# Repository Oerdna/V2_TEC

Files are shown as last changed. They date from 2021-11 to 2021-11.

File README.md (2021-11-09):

# V2_TEC
Redesigned PCB for simultaneous Peltier control and surface resistance measurement

------

## Composition
The complex consists of two boards - Signal and Power. The power acts like as a controller of the Peltier element. Signal measures surface resistance and temperature.
In the table, the top line is the signal board. Lower - power. Drawings as part of a work of art.

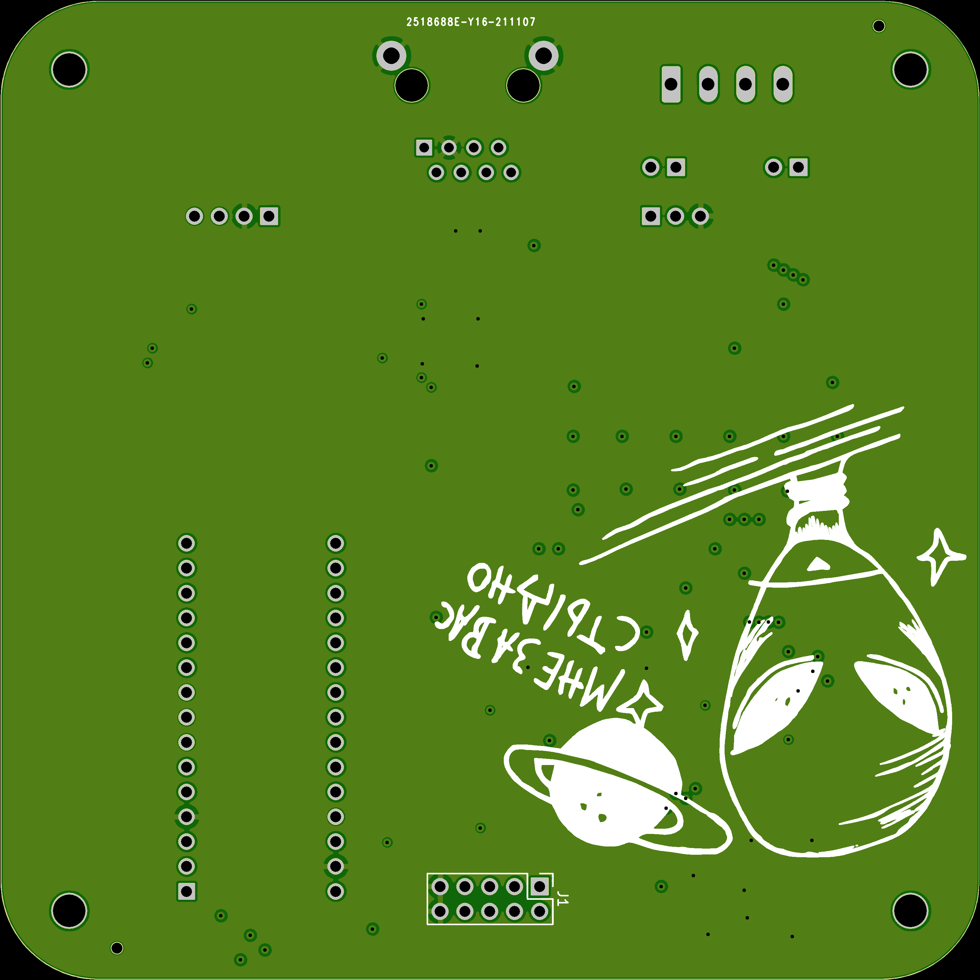
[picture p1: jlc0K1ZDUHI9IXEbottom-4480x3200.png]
Signal_top
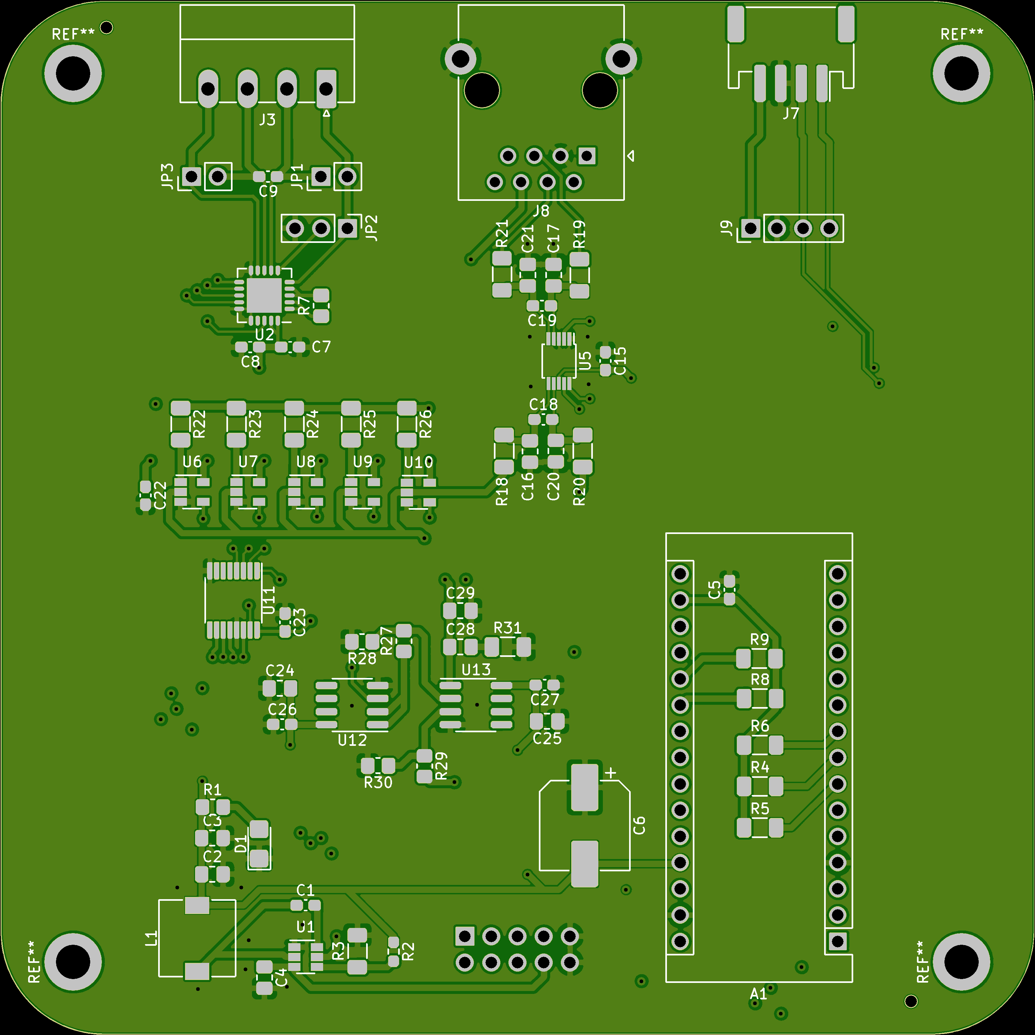
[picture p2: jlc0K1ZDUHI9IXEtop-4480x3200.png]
Signal_back
|  |  |
| --- | --- |
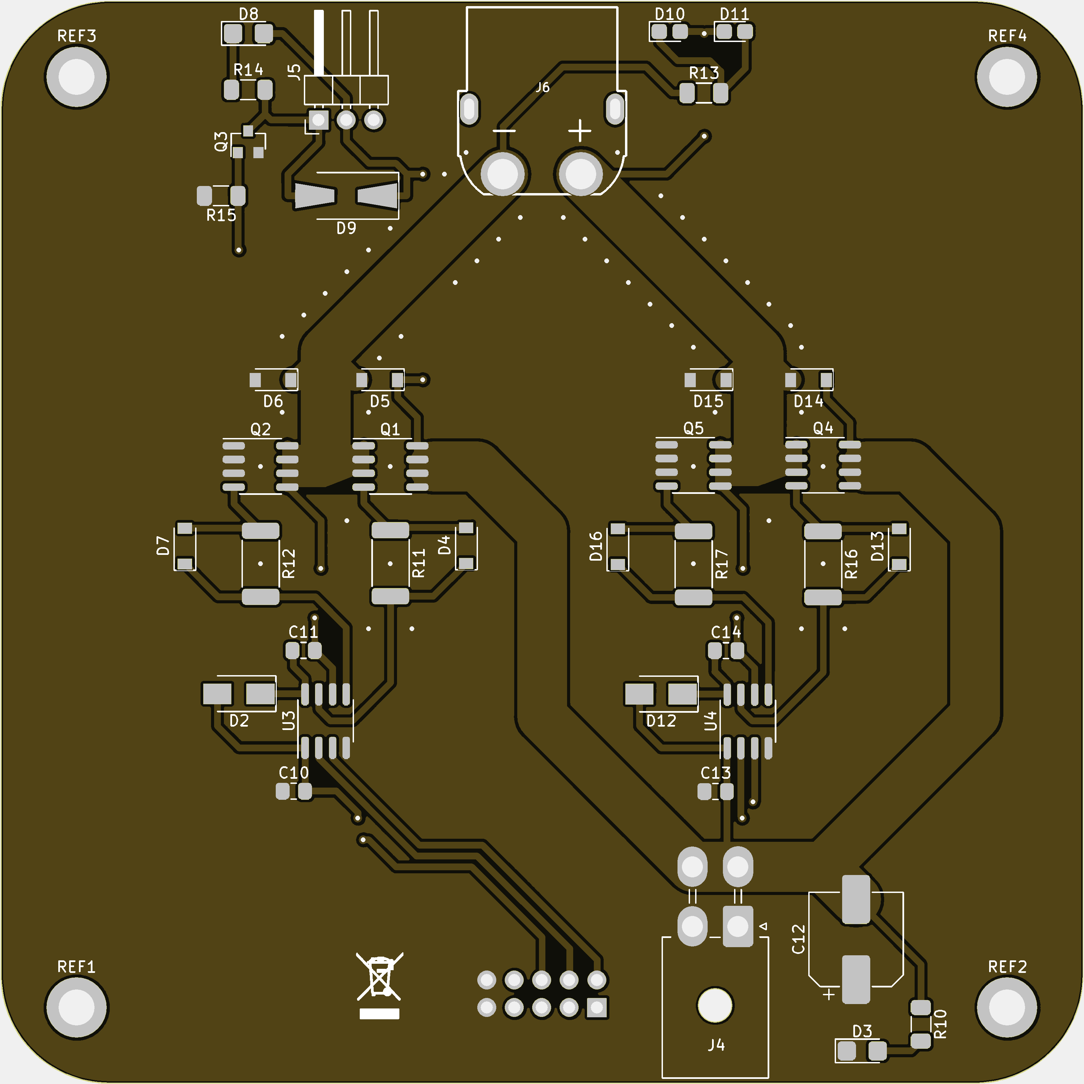
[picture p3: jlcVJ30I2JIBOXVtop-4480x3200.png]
Power_top
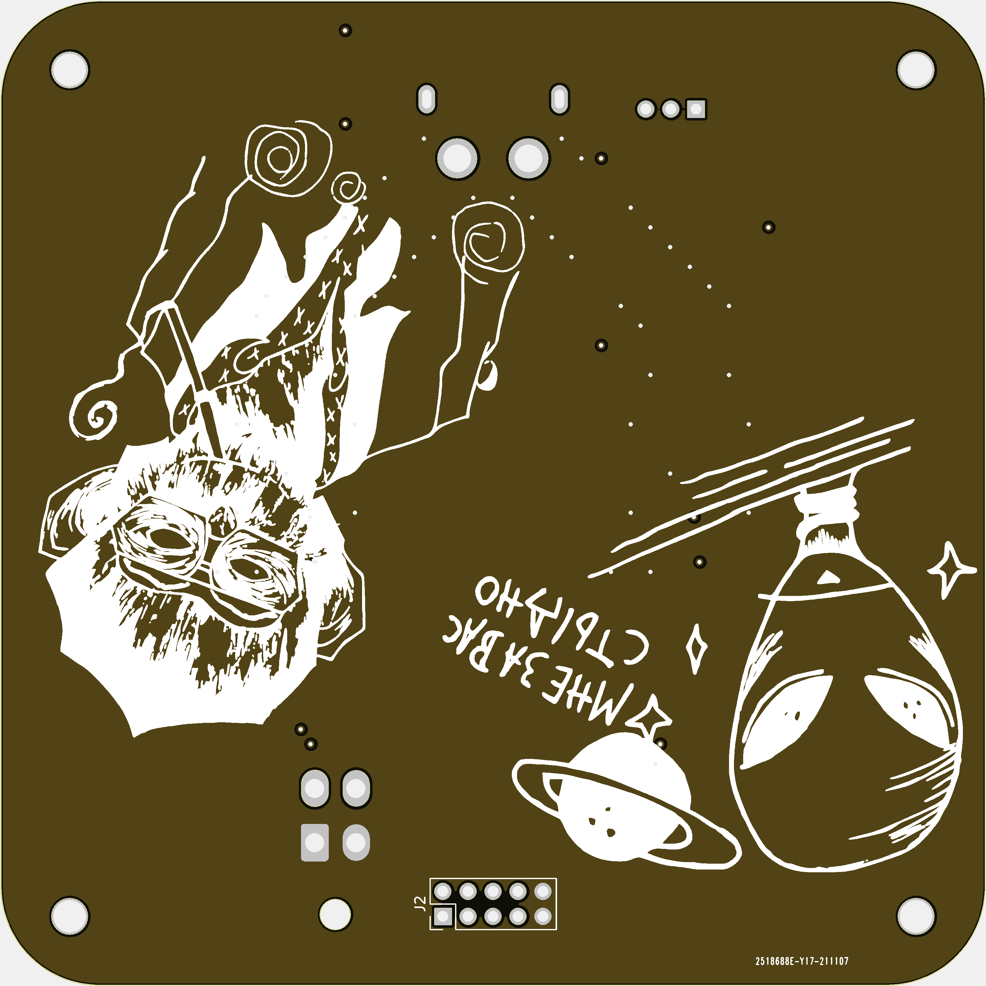
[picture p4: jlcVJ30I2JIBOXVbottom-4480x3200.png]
Power_back
|  |  |

More details about the device can be understood from the schematic drawing [here](https://github.com/Oerdna/V2_TEC/blob/main/TEC2/TEC2.pdf). The notes are in Russian.

The controller for the complex is `STM32L432KC Nucleo`.

## Reference Information:
* To control the Peltier element, a `100 kHz PWM` is used.
* `IRS2104` is used to control transistors.
* The measurement of surface resistance is carried out by the `four-probe method`.
* Temperature measurement is carried out by `pt100`.
* There is an additional port for the `I2C` protocol

## 4point_probe

 | 4PP | Four point probe is used to measure resistive properties of semiconductor wafers and thin films [[1](https://www.pveducation.org/pvcdrom/characterisation/four-point-probe-resistivity-measurements)]. |
| ------------------------------------------------------------ | ------------------------------------------------------------ |

In this case are studing the I - V characteristic of an element depending on the temperature of the sample. It is important to understand the I – V characteristic near the metal-insulator phase transition (MIT), which is about 68 degrees Celsius. You must understand that the ultimate goal is to stabilize the temperature to a specific value. More about the TEC control [[2](https://www.maximintegrated.com/en/design/technical-documents/tutorials/1/1757.html)]

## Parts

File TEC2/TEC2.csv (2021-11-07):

Comment | Designator | Footprint | LCSC
Arduino_Nano_v3.x | A1 | Module:Arduino_Nano | ~
1uF | C11,C14 | Capacitor_SMD:C_0805_2012Metric_Pad1.18x1.45mm_HandSolder | C28323
6nF | C16,C17,C20,C21,C29 | Capacitor_SMD:C_0805_2012Metric_Pad1.18x1.45mm_HandSolder | C1755
62nF | C18,C19 | Capacitor_SMD:C_0603_1608Metric_Pad1.08x0.95mm_HandSolder | C31658
470nf | C28 | Capacitor_SMD:C_0805_2012Metric_Pad1.18x1.45mm_HandSolder | C13967
10uF | C2,C3,C4,C10,C13,C24,C25 | Capacitor_SMD:C_0805_2012Metric_Pad1.18x1.45mm_HandSolder | C440198
100nF | C1,C5,C7,C8,C9,C15,C22,C23,C26,C27 | Capacitor_SMD:C_0603_1608Metric_Pad1.08x0.95mm_HandSolder | C14663
220uF | C6,C12 | Capacitor_SMD:CP_Elec_8x10.5 | ~
5V_LED | D1 | LED_SMD:LED_1206_3216Metric_Castellated | ~
LED | D10,D11 | LED_SMD:LED_0805_2012Metric_Castellated | ~
US2MA | D2,D12 | Diode_SMD:D_SMA | ~
1N4148W | D4,D5,D6,D7,D13,D14,D15,D16 | Diode_SMD:D_SOD-123 | ~
12V_LED | D3 | LED_SMD:LED_1206_3216Metric_Castellated | ~
FUN_LED | D8 | LED_SMD:LED_1206_3216Metric_Castellated | ~
1N4001 | D9 | Diode_SMD:D_SMA-SMB_Universal_Handsoldering | ~
J_PCB_UPPER | J1 | Connector_PinHeader_2.54mm:PinHeader_2x05_P2.54mm_Vertical | ~
J_PCB_DOWN | J2 | Connector_PinHeader_2.54mm:PinHeader_2x05_P2.54mm_Vertical | ~
ToPT100 | J3 | Connector_Phoenix_MC:PhoenixContact_MC_1,5_4-G-3.81_1x04_P3.81mm_Horizontal | ~
IN_12V_POWER | J4 | Connector_Molex:Molex_Mini-Fit_Jr_5569-04A2_2x02_P4.20mm_Horizontal | ~
J_COOLER | J5 | Connector_PinHeader_2.54mm:PinHeader_1x03_P2.54mm_Horizontal | ~
J_TERMO | J6 | XT60-PW:Amass_XT60PW-M | ~
I2C_Port | J7 | Connector_JST:JST_PH_S4B-PH-SM4-TB_1x04-1MP_P2.00mm_Horizontal | ~
RJ45_Shielded | J8 | Connector_RJ:RJ45_Ninigi_GE | ~
I2C_dbg | J9 | Connector_PinHeader_2.54mm:PinHeader_1x04_P2.54mm_Vertical | ~
SJ2 | JP1 | Connector_PinHeader_2.54mm:PinHeader_1x02_P2.54mm_Vertical | ~
SJ1 | JP2 | Connector_PinHeader_2.54mm:PinHeader_1x03_P2.54mm_Vertical | ~
SJ3 | JP3 | Connector_PinHeader_2.54mm:PinHeader_1x02_P2.54mm_Vertical | ~
4.7uH | L1 | Inductor_SMD:L_7.3x7.3_H4.5 | ~
FDV303N | Q3 | Package_TO_SOT_SMD:SOT-23 | ~
IRF7403 | Q1,Q2,Q4,Q5 | Package_SO:SOIC-8_3.9x4.9mm_P1.27mm | ~
430 | R1 | Resistor_SMD:R_0805_2012Metric_Pad1.20x1.40mm_HandSolder | C17710
1k | R10,R13,R14,R15,R25 | Resistor_SMD:R_1206_3216Metric_Pad1.30x1.75mm_HandSolder | C4410
47 | R11,R12,R16,R17 | Resistor_SMD:R_2512_6332Metric_Pad1.40x3.35mm_HandSolder | ~
56.2k | R2 | Resistor_SMD:R_0603_1608Metric_Pad0.98x0.95mm_HandSolder | C23206
1 | R22 | Resistor_SMD:R_1206_3216Metric_Pad1.30x1.75mm_HandSolder | C17928
10 | R23 | Resistor_SMD:R_1206_3216Metric_Pad1.30x1.75mm_HandSolder | C17903
20k | R27,R30 | Resistor_SMD:R_0805_2012Metric_Pad1.20x1.40mm_HandSolder | C4328
13k | R28,R29 | Resistor_SMD:R_0805_2012Metric_Pad1.20x1.40mm_HandSolder | C17455
100 | R18,R19,R20,R21,R24,R31 | Resistor_SMD:R_1206_3216Metric_Pad1.30x1.75mm_HandSolder | C17901
390 | R7 | Resistor_SMD:R_0805_2012Metric_Pad1.20x1.40mm_HandSolder | C17655
10k | R3,R4,R5,R6,R8,R9,R26 | Resistor_SMD:R_1206_3216Metric_Pad1.30x1.75mm_HandSolder | C17902
TPS562200 | U1 | Package_TO_SOT_SMD:SOT-23-6 | ~
TS5A3166DBVR | U6,U7,U8,U9,U10 | Package_TO_SOT_SMD:SOT-23-5 | ~
74HC595 | U11 | Package_SO:TSSOP-16_4.4x5mm_P0.65mm | ~
AD8572 | U12 | Package_SO:SOIC-8_3.9x4.9mm_P1.27mm | ~
AD8606ARZ | U13 | Package_SO:SOIC-8_3.9x4.9mm_P1.27mm | ~
MAX31865xTP | U2 | Package_DFN_QFN:TQFN-20-1EP_5x5mm_P0.65mm_EP3.25x3.25mm | ~
IR2104 | U3,U4 | Package_SO:SOIC-8_3.9x4.9mm_P1.27mm | ~
ADS1115IDGS | U5 | Package_SO:TSSOP-10_3x3mm_P0.5mm | ~

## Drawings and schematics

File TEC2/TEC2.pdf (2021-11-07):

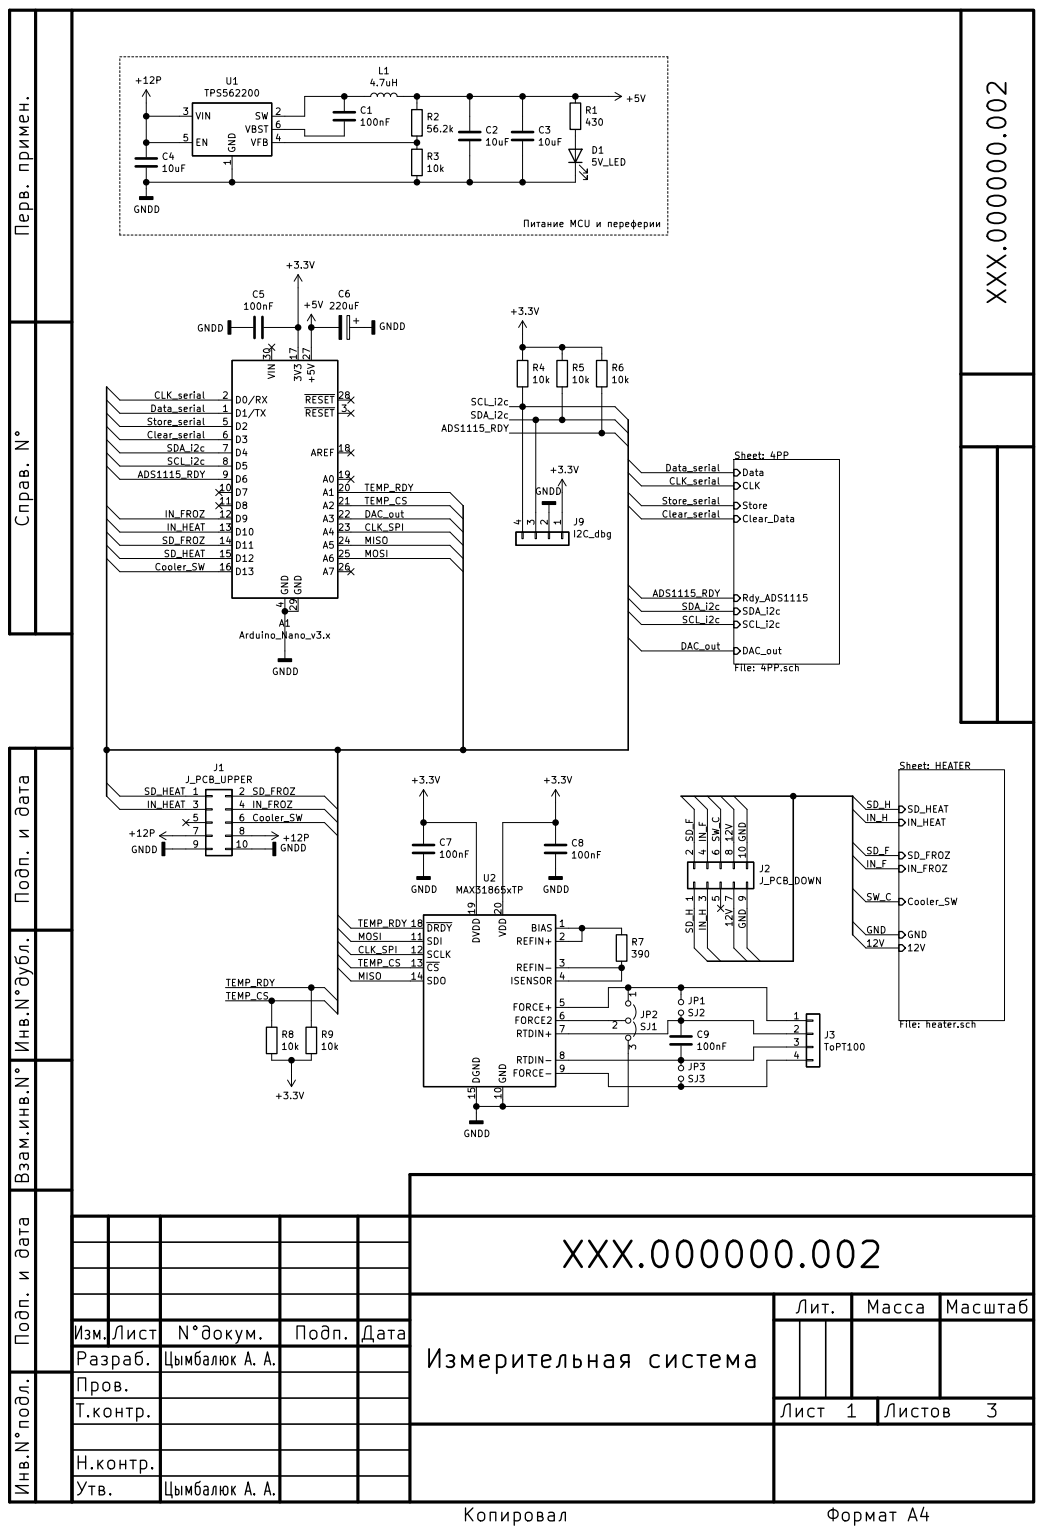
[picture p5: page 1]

1 SW 2 VIN 3 VFB 4 EN 5 VBST 6 U1 TPS562200 GNDD

Sheet: 4PP
File: 4PP.sch SCL_i2c SDA_i2c Data Clear_Data CLK
Store DAC_out Rdy_ADS1115

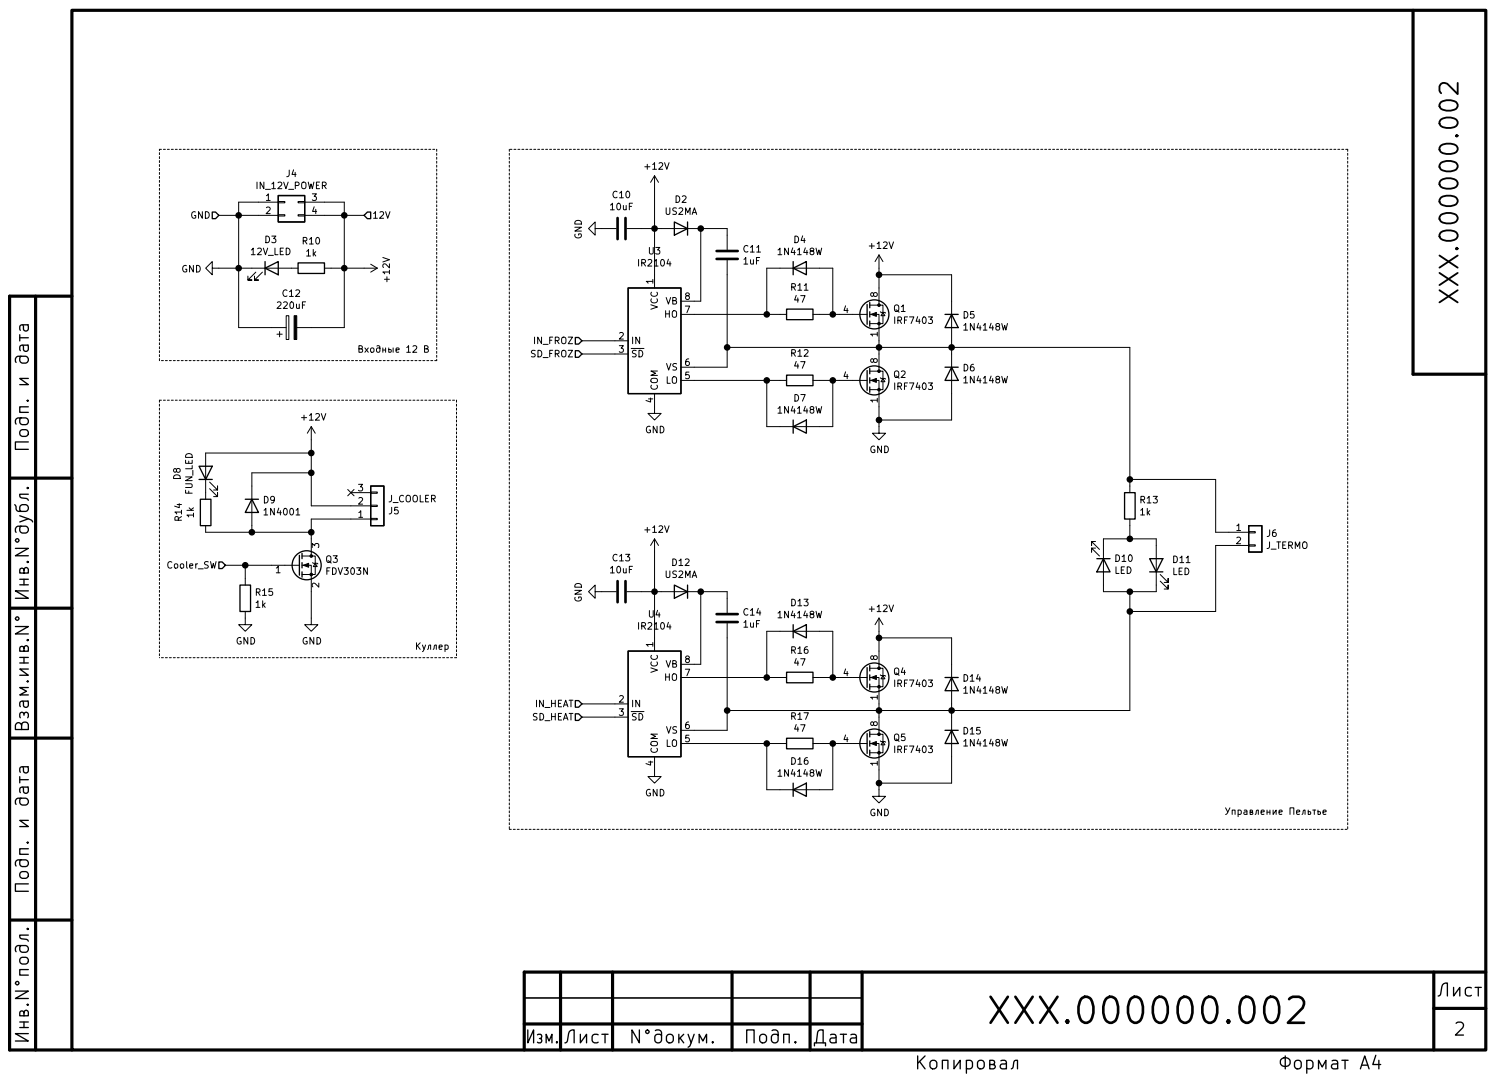
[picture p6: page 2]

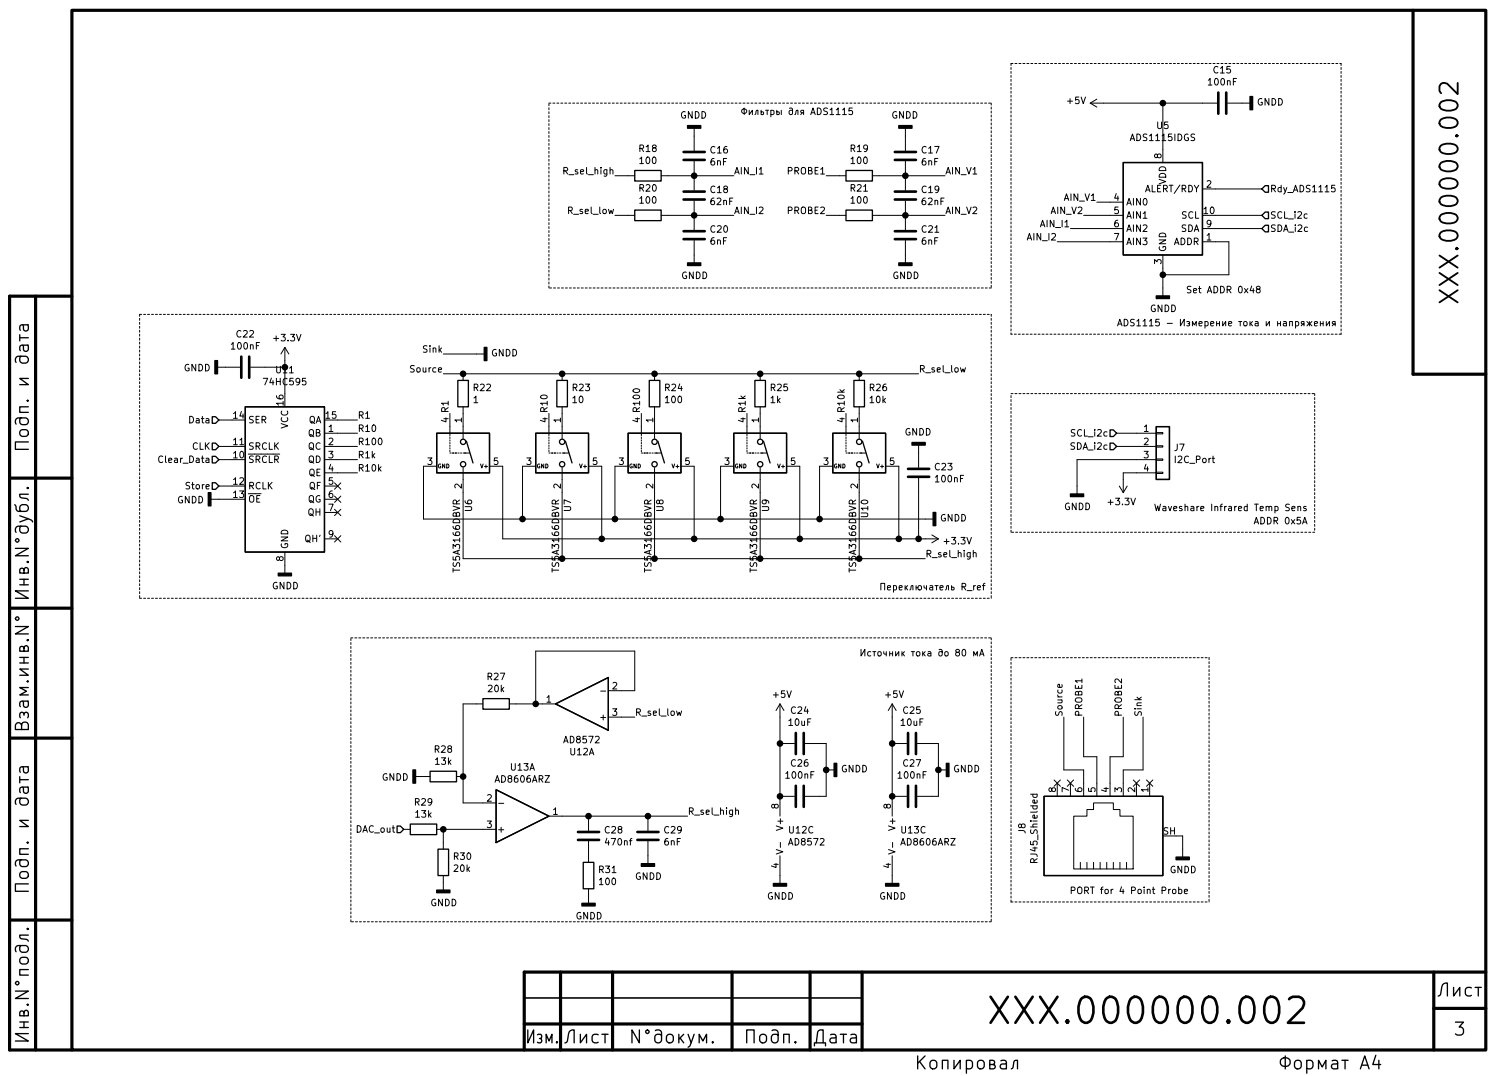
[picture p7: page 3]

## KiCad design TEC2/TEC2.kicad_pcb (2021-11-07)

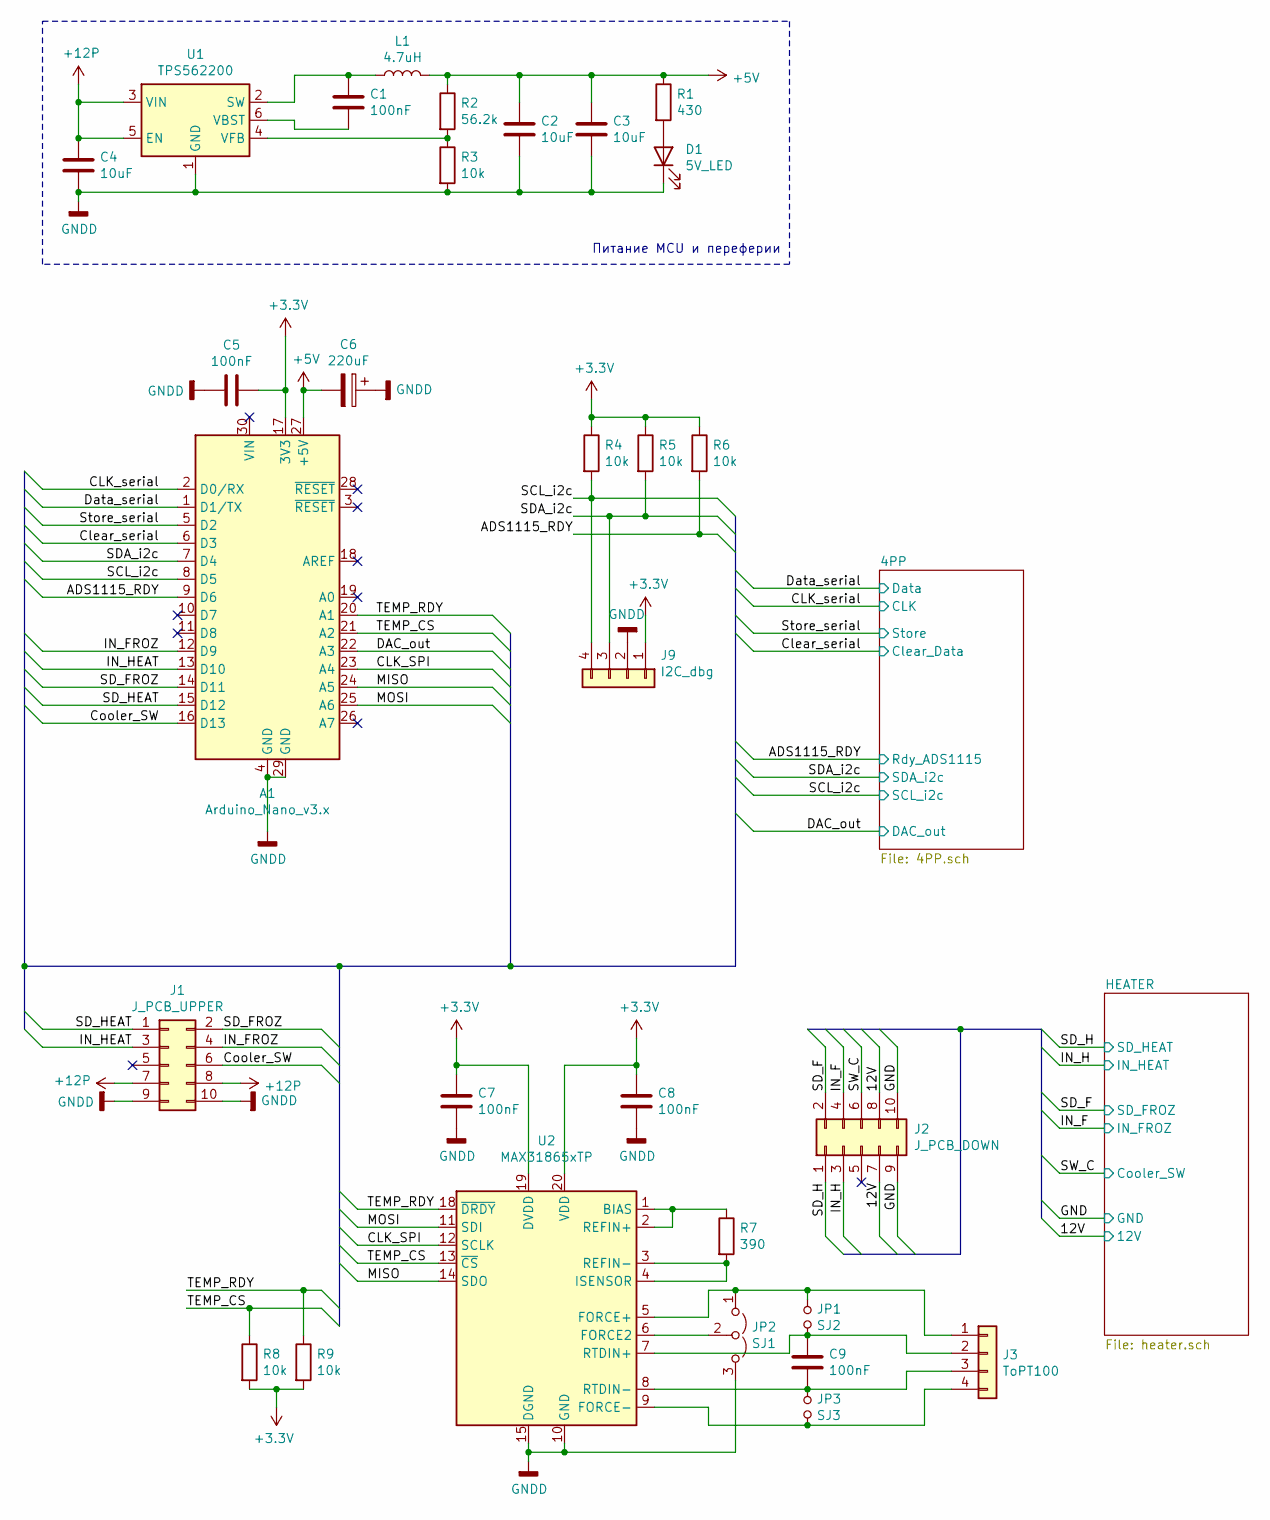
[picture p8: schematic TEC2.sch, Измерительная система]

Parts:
A1: Arduino_Nano_v3.x; Arduino_Nano
C1, C5, C7, C8, C9: 100nF; C_0603_1608Metric_Pad1.08x0.95mm_HandSolder; JLC 0603
C2, C3, C4: 10uF; C_0805_2012Metric_Pad1.18x1.45mm_HandSolder; JLC 0805
C6: 220uF; CP_Elec_8x10.5
D1: 5V_LED; LED_1206_3216Metric_Castellated
J1: J_PCB_UPPER; PinHeader_2x05_P2.54mm_Vertical
J2: J_PCB_DOWN; PinHeader_2x05_P2.54mm_Vertical
J3: ToPT100; PhoenixContact_MC_1,5_4-G-3.81_1x04_P3.81mm_Horizontal
J9: I2C_dbg; PinHeader_1x04_P2.54mm_Vertical
JP1: SJ2; PinHeader_1x02_P2.54mm_Vertical
JP2: SJ1; PinHeader_1x03_P2.54mm_Vertical
JP3: SJ3; PinHeader_1x02_P2.54mm_Vertical
L1: 4.7uH; L_7.3x7.3_H4.5
R1: 430; R_0805_2012Metric_Pad1.20x1.40mm_HandSolder; JLC 0805
R2: 56.2k; R_0603_1608Metric_Pad0.98x0.95mm_HandSolder; JLC 0603
R3, R4, R5, R6, R8, R9: 10k; R_1206_3216Metric_Pad1.30x1.75mm_HandSolder; JLC 1206
R7: 390; R_0805_2012Metric_Pad1.20x1.40mm_HandSolder; JLC 0805
U1: TPS562200; SOT-23-6
U2: MAX31865xTP; TQFN-20-1EP_5x5mm_P0.65mm_EP3.25x3.25mm

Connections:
+3V3: A1.17 (3V3), C5.1, C7.2, C8.1, J9.1, R4.1, R5.1, R6.1, R8.2, R9.2, U2.19 (DVDD), U2.20 (VDD); also elsewhere on the board
+5V: A1.27 (+5V), C2.1, C3.1, C6.2, L1.2, R1.1, R2.1; also elsewhere on the board
+12P: C4.1, J1.7, J1.8, U1.3 (VIN), U1.5 (EN)
+12V: J2.7, J2.8; also elsewhere on the board
/ADS1115_RDY: A1.9 (D6), R6.2; also elsewhere on the board
/CLK_SPI: A1.23 (A4), U2.12 (SCLK)
/CLK_serial: A1.2 (D0/RX); also elsewhere on the board
/Clear_serial: A1.6 (D3); also elsewhere on the board
/Cooler_SW: A1.16 (D13), J1.6
/DAC_out: A1.22 (A3); also elsewhere on the board
/Data_serial: A1.1 (D1/TX); also elsewhere on the board
/IN_F: J2.4; also elsewhere on the board
/IN_FROZ: A1.12 (D9), J1.4
/IN_H: J2.3; also elsewhere on the board
/IN_HEAT: A1.13 (D10), J1.3
/MISO: A1.24 (A5), U2.14 (SDO)
/MOSI: A1.25 (A6), U2.11 (SDI)
/SCL_i2c: A1.8 (D5), J9.4, R4.2; also elsewhere on the board
/SDA_i2c: A1.7 (D4), J9.3, R5.2; also elsewhere on the board
/SD_F: J2.2; also elsewhere on the board
/SD_FROZ: A1.14 (D11), J1.2
/SD_H: J2.1; also elsewhere on the board
/SD_HEAT: A1.15 (D12), J1.1
/SW_C: J2.6; also elsewhere on the board
/Store_serial: A1.5 (D2); also elsewhere on the board
/TEMP_CS: A1.21 (A2), R8.1, U2.13 (~CS)
/TEMP_RDY: A1.20 (A1), R9.1, U2.18 (~DRDY)
GND: J2.9, J2.10; also elsewhere on the board
GNDD: A1.4 (GND), A1.29 (GND), C2.2, C3.2, C4.2, C5.2, C6.1, C7.1, C8.2, D1.1 (K), J1.9, J1.10, J9.2, JP2.3 (B), R3.2, U1.1 (GND), U2.10 (GND), U2.15 (DGND), U2.16 (GND), U2.21 (GND); also elsewhere on the board
unnamed: C1.1, L1.1, U1.2 (SW)
unnamed: C1.2, U1.6 (VBST)
unnamed: C9.1, J3.2, JP1.1, U2.7 (RTDIN+)
unnamed: C9.2, J3.3, JP3.2, U2.8 (RTDIN-)
unnamed: D1.2 (A), R1.2
unnamed: J3.1, JP1.2, JP2.1 (A), U2.5 (FORCE+)
unnamed: J3.4, JP3.1, U2.9 (FORCE-)
unnamed: JP2.2 (C), U2.6 (FORCE2)
unnamed: R2.2, R3.1, U1.4 (VFB)
unnamed: R7.1, U2.1 (BIAS), U2.2 (REFIN+)
unnamed: R7.2, U2.3 (REFIN-), U2.4 (ISENSOR)

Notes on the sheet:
Питание MCU и переферии

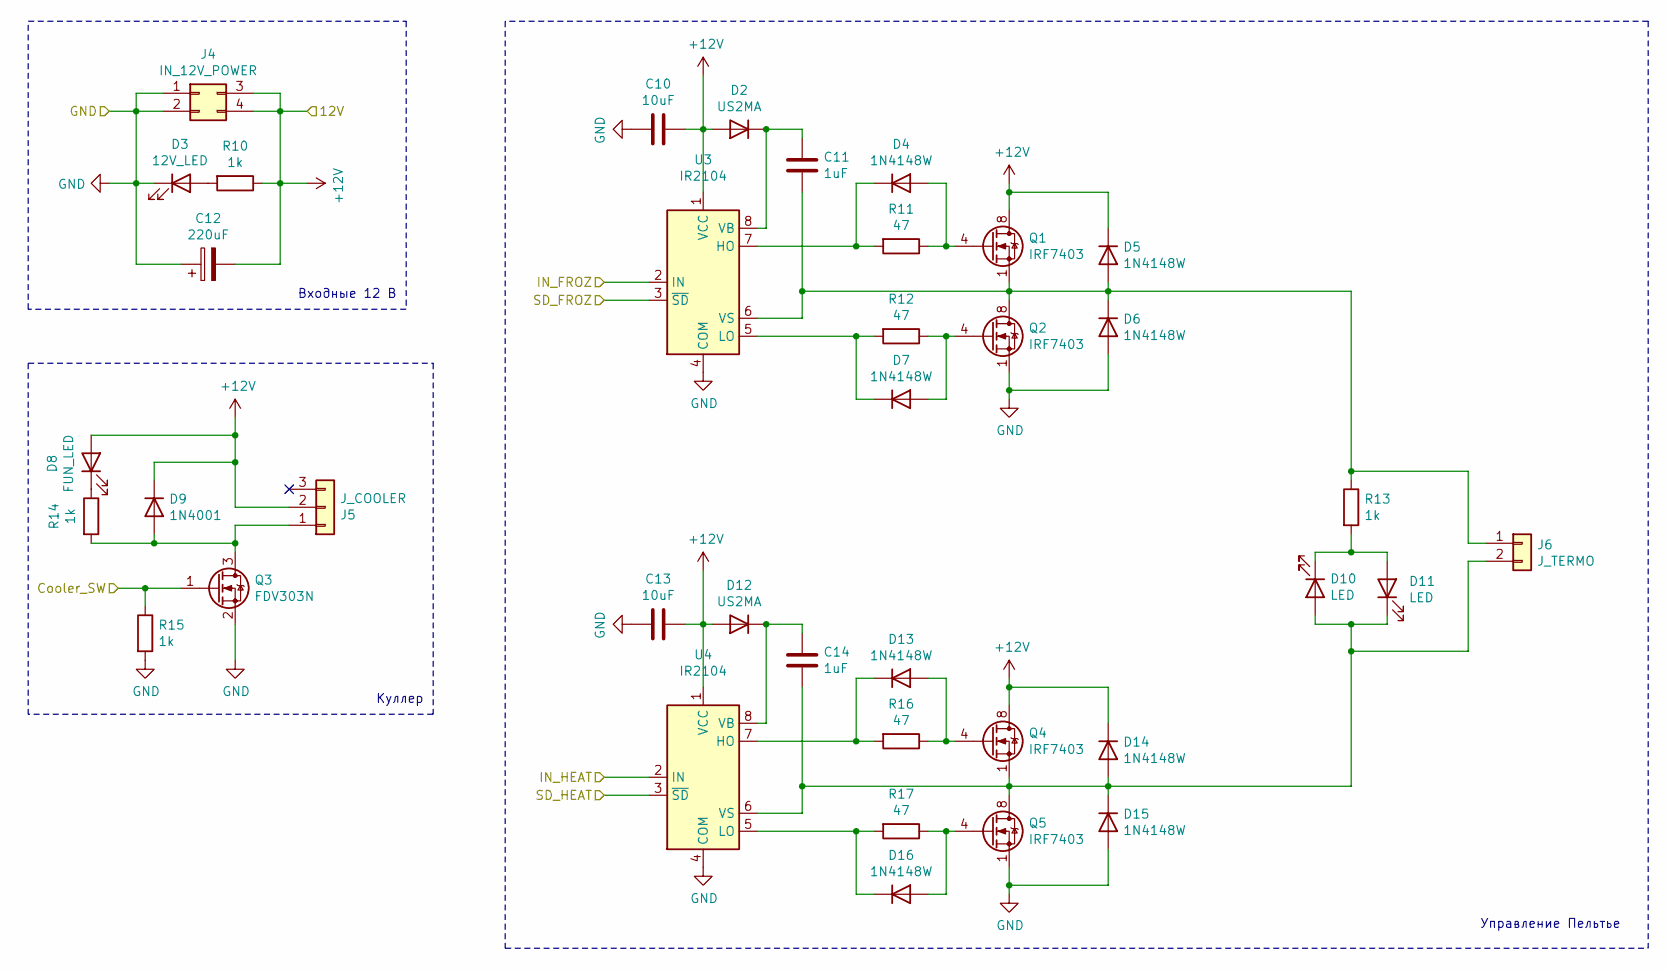
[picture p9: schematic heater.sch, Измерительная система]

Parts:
C10, C13: 10uF; C_0805_2012Metric_Pad1.18x1.45mm_HandSolder; JLC 0805
C11, C14: 1uF; C_0805_2012Metric_Pad1.18x1.45mm_HandSolder; JLC 0805
C12: 220uF; CP_Elec_8x10.5
D2, D12: US2MA; D_SMA
D3: 12V_LED; LED_1206_3216Metric_Castellated
D4, D5, D6, D7, D13, D14, D15, D16: 1N4148W; D_SOD-123
D8: FUN_LED; LED_1206_3216Metric_Castellated
D9: 1N4001; D_SMA-SMB_Universal_Handsoldering
D10, D11: LED; LED_0805_2012Metric_Castellated
J4: IN_12V_POWER; Molex_Mini-Fit_Jr_5569-04A2_2x02_P4.20mm_Horizontal
J5: J_COOLER; PinHeader_1x03_P2.54mm_Horizontal
J6: J_TERMO; Amass_XT60PW-M
Q1, Q2, Q4, Q5: IRF7403; SOIC-8_3.9x4.9mm_P1.27mm
Q3: FDV303N; SOT-23
R10, R13, R14, R15: 1k; R_1206_3216Metric_Pad1.30x1.75mm_HandSolder; JLC 1206
R11, R12, R16, R17: 47; R_2512_6332Metric_Pad1.40x3.35mm_HandSolder
U3, U4: IR2104; SOIC-8_3.9x4.9mm_P1.27mm

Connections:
+12V: C10.2, C12.2, C13.2, D2.2 (A), D5.1 (K), D8.2 (A), D9.1 (K), D12.2 (A), D14.1 (K), J4.3, J4.4, J5.2, Q1.5 (D), Q1.6 (D), Q1.7 (D), Q1.8 (D), Q4.5 (D), Q4.6 (D), Q4.7 (D), Q4.8 (D), R10.1, U3.1 (VCC), U4.1 (VCC); also elsewhere on the board
/IN_F: U3.2 (IN); also elsewhere on the board
/IN_H: U4.2 (IN); also elsewhere on the board
/SD_F: U3.3 (~SD); also elsewhere on the board
/SD_H: U4.3 (~SD); also elsewhere on the board
/SW_C: Q3.1 (G), R15.1; also elsewhere on the board
GND: C10.1, C12.1, C13.1, D3.1 (K), D6.2 (A), D15.2 (A), J4.1, J4.2, Q2.1 (S), Q2.2 (S), Q2.3 (S), Q3.2 (S), Q5.1 (S), Q5.2 (S), Q5.3 (S), R15.2, U3.4 (COM), U4.4 (COM); also elsewhere on the board
unnamed: C11.1, D2.1 (K), U3.8 (VB)
unnamed: C11.2, D5.2 (A), D6.1 (K), J6.1, Q1.1 (S), Q1.2 (S), Q1.3 (S), Q2.5 (D), Q2.6 (D), Q2.7 (D), Q2.8 (D), R13.1, U3.6 (VS)
unnamed: C14.1, D12.1 (K), U4.8 (VB)
unnamed: C14.2, D10.2 (A), D11.1 (K), D14.2 (A), D15.1 (K), J6.2, Q4.1 (S), Q4.2 (S), Q4.3 (S), Q5.5 (D), Q5.6 (D), Q5.7 (D), Q5.8 (D), U4.6 (VS)
unnamed: D3.2 (A), R10.2
unnamed: D4.1 (K), R11.2, U3.7 (HO)
unnamed: D4.2 (A), Q1.4 (G), R11.1
unnamed: D7.1 (K), R12.2, U3.5 (LO)
unnamed: D7.2 (A), Q2.4 (G), R12.1
unnamed: D8.1 (K), R14.1
unnamed: D9.2 (A), J5.1, Q3.3 (D), R14.2
unnamed: D10.1 (K), D11.2 (A), R13.2
unnamed: D13.1 (K), R16.2, U4.7 (HO)
unnamed: D13.2 (A), Q4.4 (G), R16.1
unnamed: D16.1 (K), R17.2, U4.5 (LO)
unnamed: D16.2 (A), Q5.4 (G), R17.1

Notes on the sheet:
Куллер
Управление Пельтье
Входные 12 В

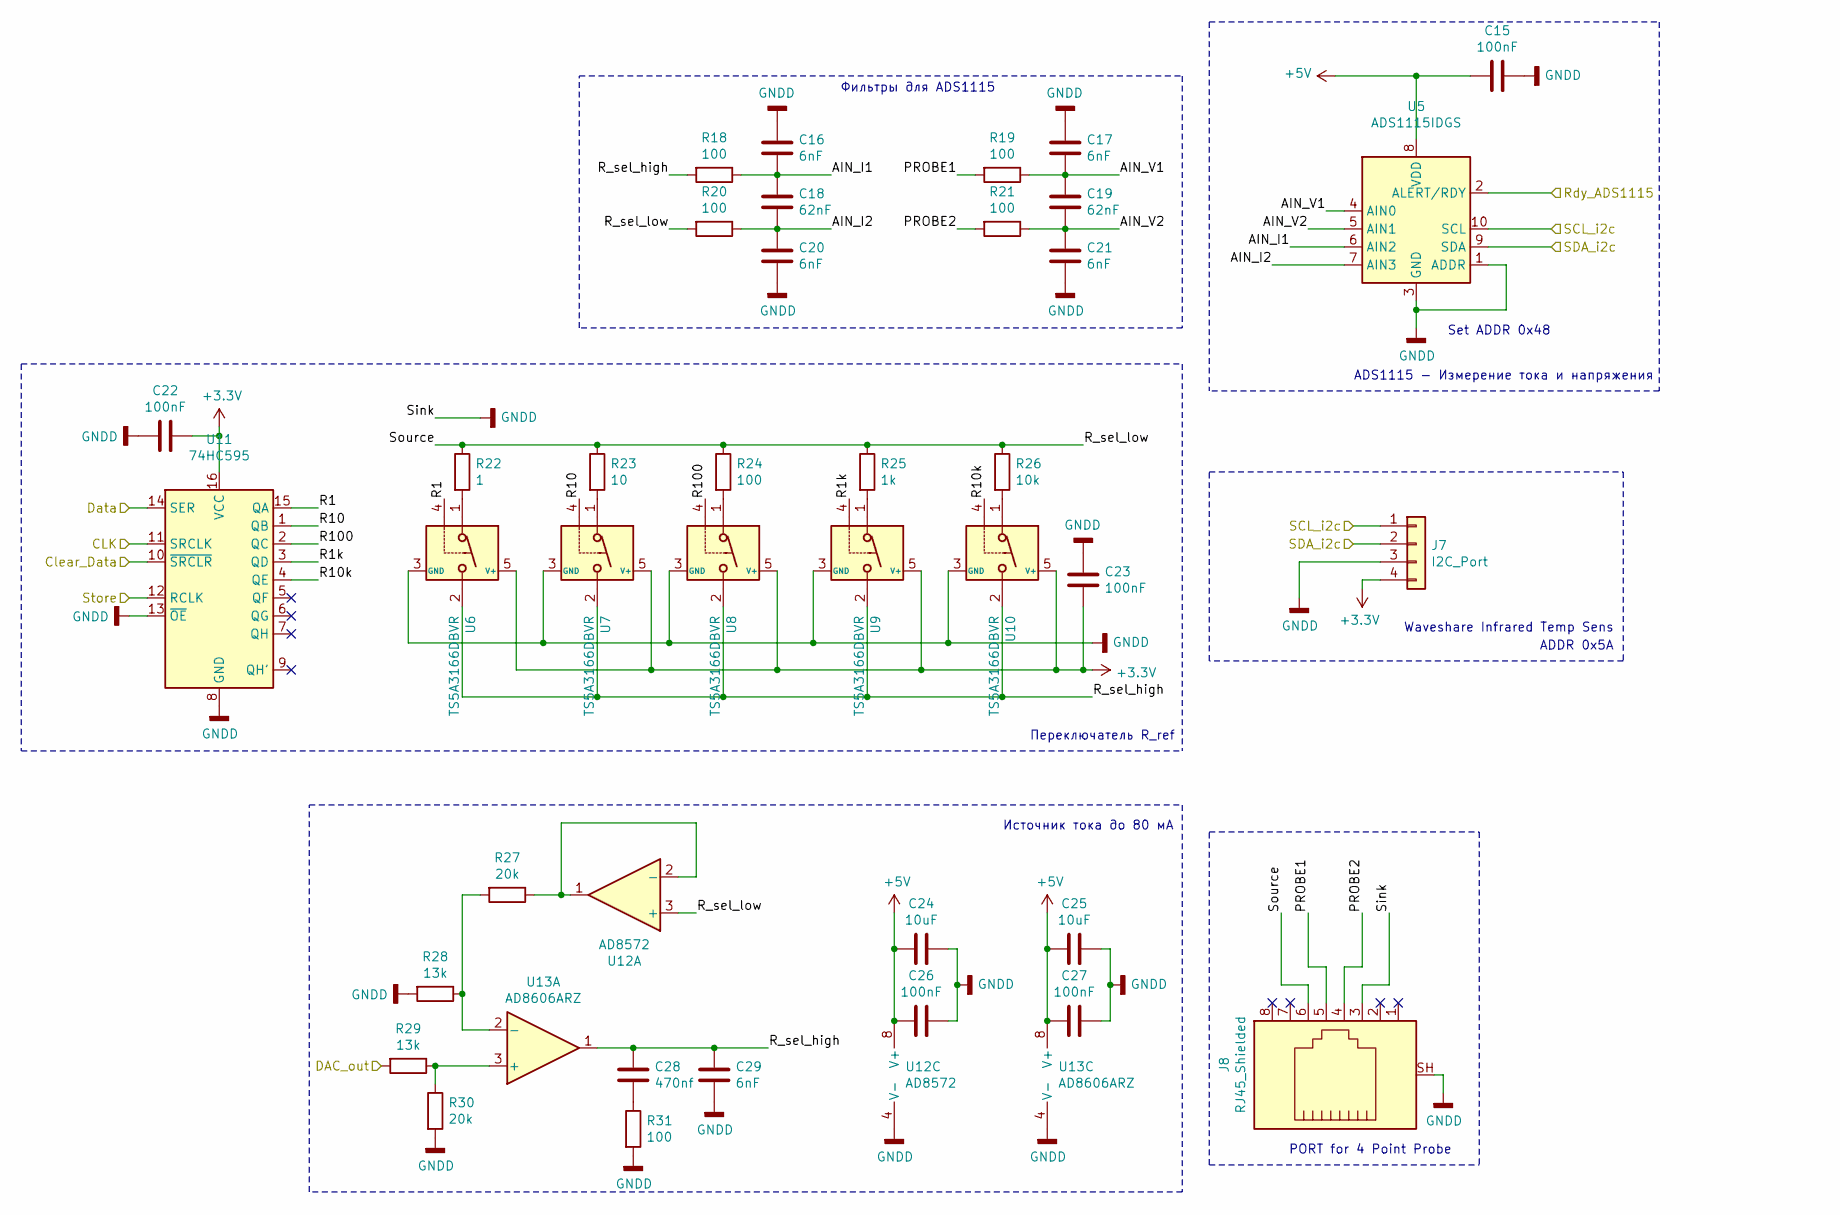
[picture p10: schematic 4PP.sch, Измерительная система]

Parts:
C15, C22, C23, C26, C27: 100nF; C_0603_1608Metric_Pad1.08x0.95mm_HandSolder; JLC 0603
C16, C17, C20, C21, C29: 6nF; C_0805_2012Metric_Pad1.18x1.45mm_HandSolder; JLC 0805
C18, C19: 62nF; C_0603_1608Metric_Pad1.08x0.95mm_HandSolder; JLC 0603
C24, C25: 10uF; C_0805_2012Metric_Pad1.18x1.45mm_HandSolder; JLC 0805
C28: 470nf; C_0805_2012Metric_Pad1.18x1.45mm_HandSolder; JLC 0805
J7: I2C_Port; JST_PH_S4B-PH-SM4-TB_1x04-1MP_P2.00mm_Horizontal
J8: RJ45_Shielded; RJ45_Ninigi_GE
R18, R19, R20, R21, R24, R31: 100; R_1206_3216Metric_Pad1.30x1.75mm_HandSolder; JLC 1206
R22: 1; R_1206_3216Metric_Pad1.30x1.75mm_HandSolder; JLC 1206
R23: 10; R_1206_3216Metric_Pad1.30x1.75mm_HandSolder; JLC 1206
R25: 1k; R_1206_3216Metric_Pad1.30x1.75mm_HandSolder; JLC 1206
R26: 10k; R_1206_3216Metric_Pad1.30x1.75mm_HandSolder; JLC 1206
R27, R30: 20k; R_0805_2012Metric_Pad1.20x1.40mm_HandSolder; JLC 0805
R28, R29: 13k; R_0805_2012Metric_Pad1.20x1.40mm_HandSolder; JLC 0805
U5: ADS1115IDGS; TSSOP-10_3x3mm_P0.5mm
U6, U7, U8, U9, U10: TS5A3166DBVR; SOT-23-5
U11: 74HC595; TSSOP-16_4.4x5mm_P0.65mm
U12: AD8572; SOIC-8_3.9x4.9mm_P1.27mm
U13: AD8606ARZ; SOIC-8_3.9x4.9mm_P1.27mm

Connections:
+3V3: C22.1, C23.2, J7.4, U6.5 (V+), U7.5 (V+), U8.5 (V+), U9.5 (V+), U10.5 (V+), U11.16 (VCC); also elsewhere on the board
+5V: C15.2, C24.2, C25.2, C26.2, C27.2, U5.8 (VDD), U12.8 (V+), U13.8 (V+); also elsewhere on the board
/4PP/AIN_I1: C16.2, C18.1, R18.1, U5.6 (AIN2)
/4PP/AIN_I2: C18.2, C20.1, R20.1, U5.7 (AIN3)
/4PP/AIN_V1: C17.2, C19.1, R19.1, U5.4 (AIN0)
/4PP/AIN_V2: C19.2, C21.1, R21.1, U5.5 (AIN1)
/4PP/PROBE1: J8.5, R19.2
/4PP/PROBE2: J8.4, R21.2
/4PP/R1: U6.4, U11.15 (QA)
/4PP/R1k: U9.4, U11.3 (QD)
/4PP/R10: U7.4, U11.1 (QB)
/4PP/R10k: U10.4, U11.4 (QE)
/4PP/R100: U8.4, U11.2 (QC)
/4PP/R_sel_high: C28.1, C29.1, R18.2, U6.2, U7.2, U8.2, U9.2, U10.2, U13.1
/4PP/R_sel_low: J8.6, R20.2, R22.1, R23.1, R24.1, R25.1, R26.1, U12.3 (+)
/ADS1115_RDY: U5.2 (ALERT/RDY); also elsewhere on the board
/CLK_serial: U11.11 (SRCLK); also elsewhere on the board
/Clear_serial: U11.10 (~SRCLR); also elsewhere on the board
/DAC_out: R29.2; also elsewhere on the board
/Data_serial: U11.14 (SER); also elsewhere on the board
/SCL_i2c: J7.1, U5.10 (SCL); also elsewhere on the board
/SDA_i2c: J7.2, U5.9 (SDA); also elsewhere on the board
/Store_serial: U11.12 (RCLK); also elsewhere on the board
GNDD: C15.1, C16.1, C17.1, C20.2, C21.2, C22.2, C23.1, C24.1, C25.1, C26.1, C27.1, C29.2, J7.3, J8.3, J8.SH, R28.2, R30.2, R31.2, U5.1 (ADDR), U5.3 (GND), U6.3 (GND), U7.3 (GND), U8.3 (GND), U9.3 (GND), U10.3 (GND), U11.8 (GND), U11.13 (~OE), U12.4 (V-), U13.4 (V-); also elsewhere on the board
unnamed: C28.2, R31.1
unnamed: R22.2, U6.1
unnamed: R23.2, U7.1
unnamed: R24.2, U8.1
unnamed: R25.2, U9.1
unnamed: R26.2, U10.1
unnamed: R27.1, U12.1, U12.2 (-)
unnamed: R27.2, R28.1, U13.2 (-)
unnamed: R29.1, R30.1, U13.3 (+)

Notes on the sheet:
Set ADDR 0x48
Источник тока до 80 мА
Переключатель R_ref
Фильтры для ADS1115
ADS1115 - Измерение тока и напряжения
Waveshare Infrared Temp Sens
ADDR 0x5A
PORT for 4 Point Probe

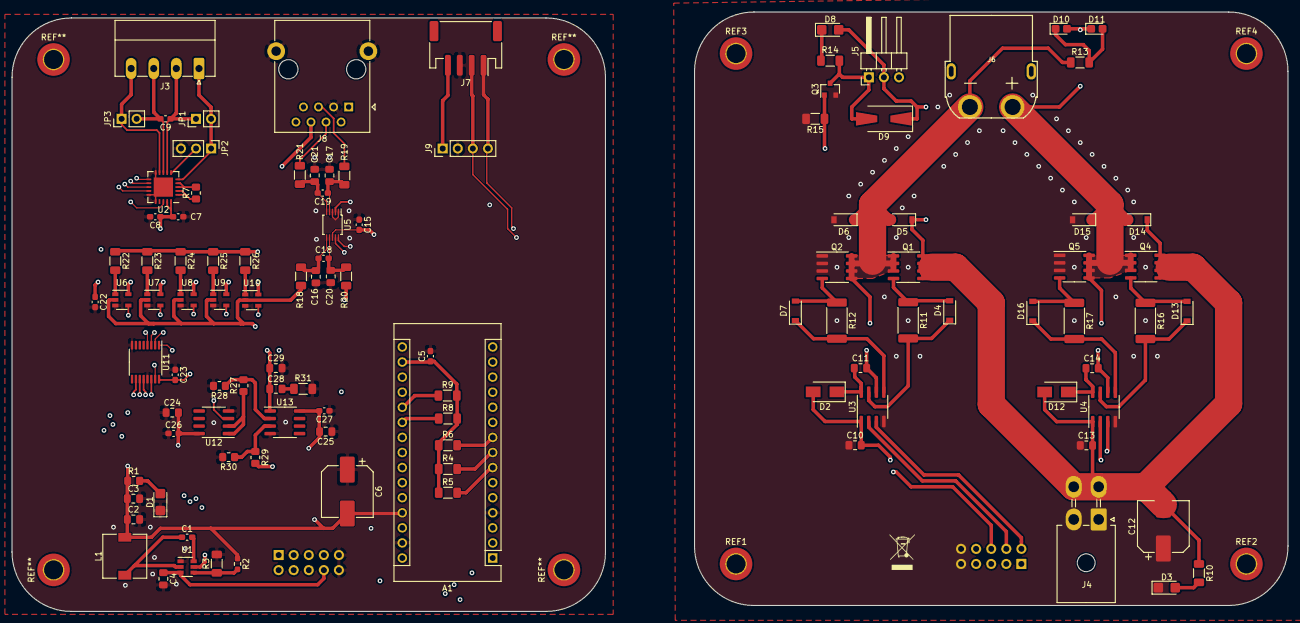
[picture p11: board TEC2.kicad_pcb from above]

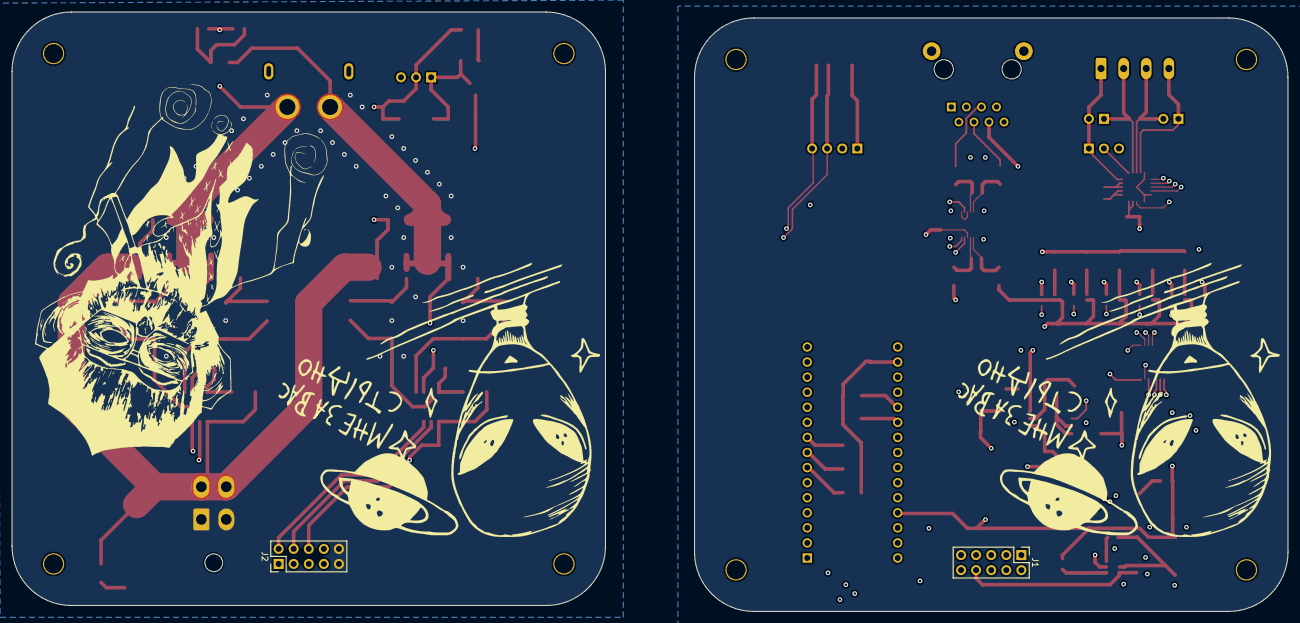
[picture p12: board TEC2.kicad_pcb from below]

Board: 4 copper layers, 215.0 x 101.0 mm, 112 parts (2 on the bottom side), 78 nets.

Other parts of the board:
REF1, REF2, REF3, REF4: MountingHole_3.2mm_M3_ISO14580_Pad_TopOnly
